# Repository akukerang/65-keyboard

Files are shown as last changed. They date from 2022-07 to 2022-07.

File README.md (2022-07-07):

# 65-keyboard
- 65% keyboard PCB for PCB design practice. 
- Used masterzen's guide for keyboard design: https://www.masterzen.fr/2020/05/03/designing-a-keyboard-part-1/
- Probably not going to add LEDs, too much routing.
## Pictures
### PCB Design
PCB Design
### PCB Top
PCB Top
### PCB Bottom
PCB Bottom

Poom

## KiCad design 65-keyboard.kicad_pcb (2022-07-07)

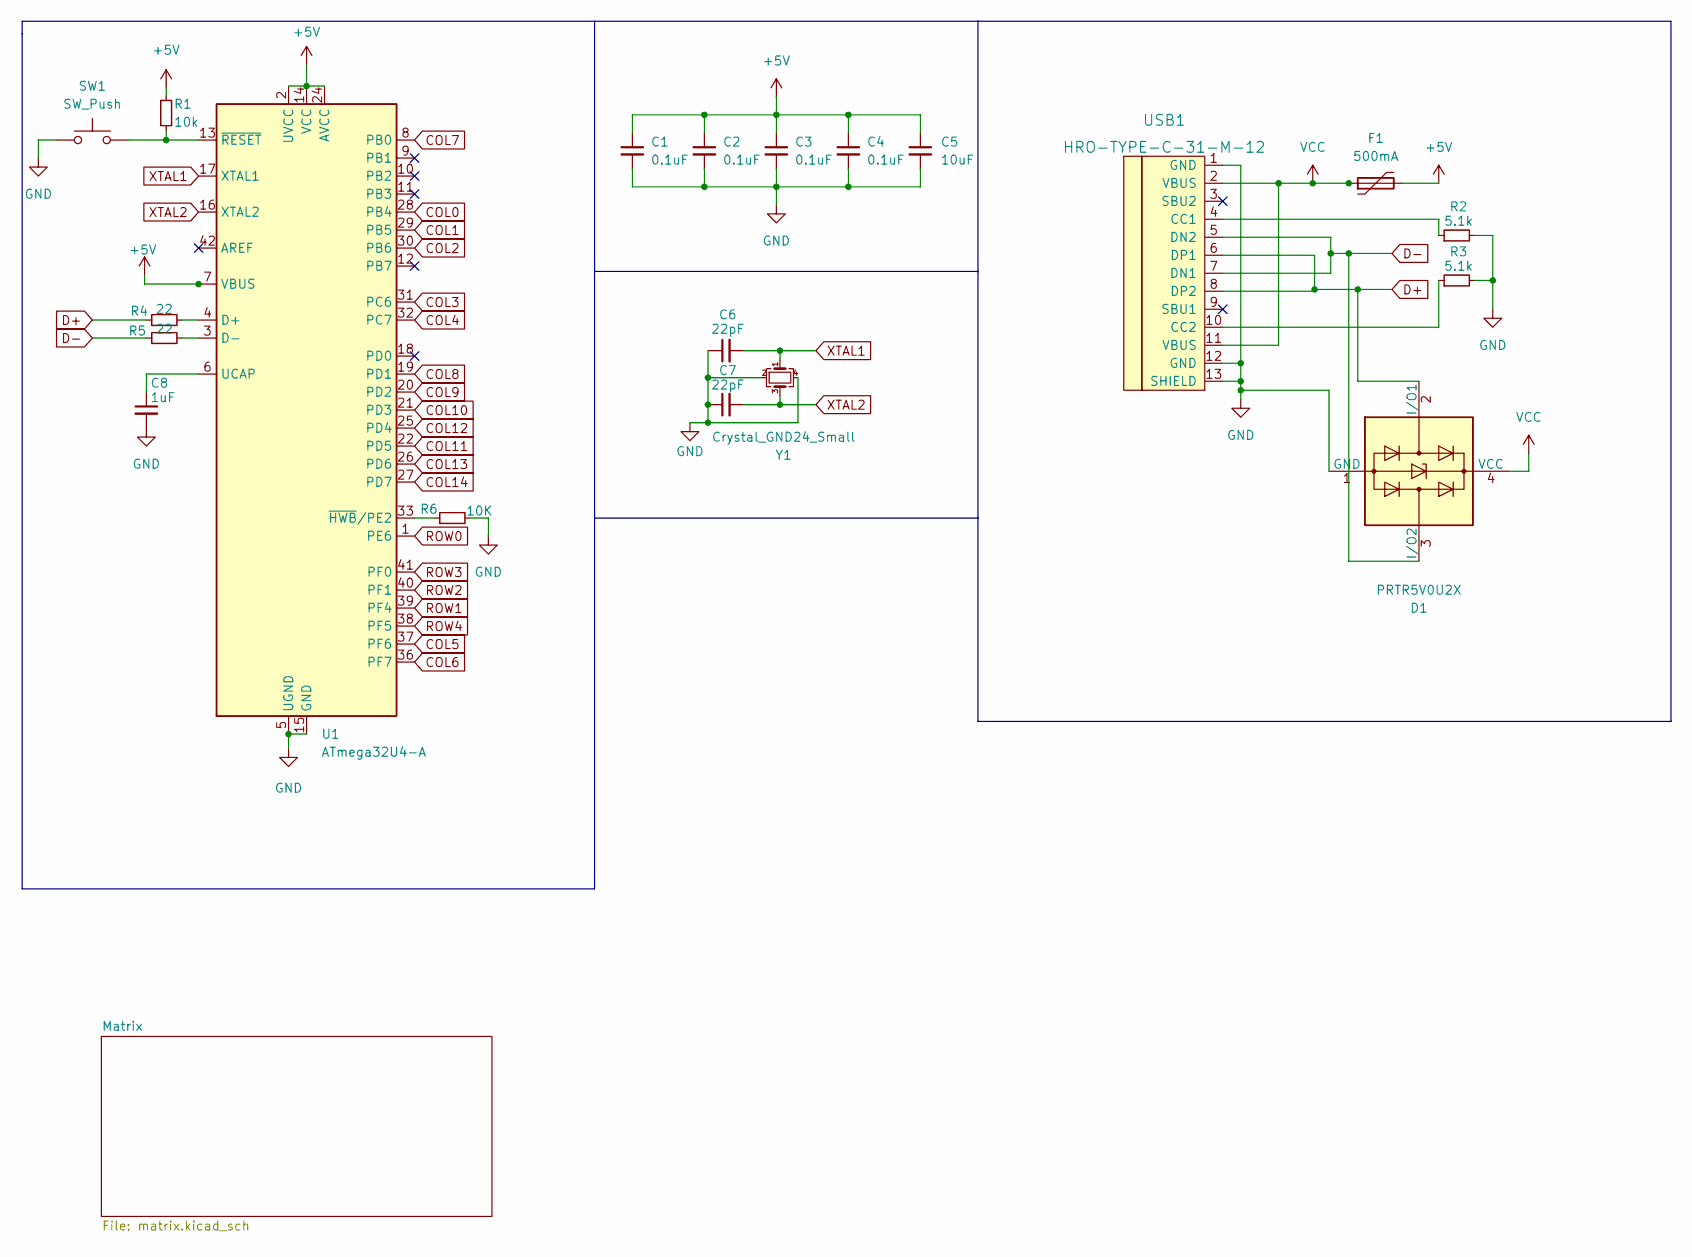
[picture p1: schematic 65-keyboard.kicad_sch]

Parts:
C1, C2, C3, C4: 0.1uF; C_0805_2012Metric_Pad1.18x1.45mm_HandSolder
C5: 10uF; C_0805_2012Metric_Pad1.18x1.45mm_HandSolder
C6, C7: 22pF; C_0805_2012Metric_Pad1.18x1.45mm_HandSolder
C8: 1uF; C_0805_2012Metric_Pad1.18x1.45mm_HandSolder
D1: PRTR5V0U2X; SOT143B
F1: 500mA; Fuse_1206_3216Metric_Pad1.42x1.75mm_HandSolder
R1: 10k; R_0805_2012Metric_Pad1.20x1.40mm_HandSolder
R2, R3: 5.1k; R_0805_2012Metric_Pad1.20x1.40mm_HandSolder
R4, R5: 22; R_0805_2012Metric_Pad1.20x1.40mm_HandSolder
R6: 10K; R_0805_2012Metric_Pad1.20x1.40mm_HandSolder
SW1: SW_Push; SW_SPST_SKQG_WithStem
U1: ATmega32U4-A; TQFP-44_10x10mm_P0.8mm
USB1: HRO-TYPE-C-31-M-12; HRO-TYPE-C-31-M-12-HandSoldering
Y1: Crystal_GND24_Small; Crystal_SMD_3225-4Pin_3.2x2.5mm_HandSoldering

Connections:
+5V: C1.1, C2.1, C3.1, C4.1, C5.1, F1.2, R1.1, U1.2 (UVCC), U1.7 (VBUS), U1.14 (VCC), U1.24 (AVCC), U1.34 (VCC), U1.44 (AVCC)
COL0: U1.28 (PB4); also elsewhere on the board
COL1: U1.29 (PB5); also elsewhere on the board
COL2: U1.30 (PB6); also elsewhere on the board
COL3: U1.31 (PC6); also elsewhere on the board
COL4: U1.32 (PC7); also elsewhere on the board
COL5: U1.37 (PF6); also elsewhere on the board
COL6: U1.36 (PF7); also elsewhere on the board
COL7: U1.8 (PB0); also elsewhere on the board
COL8: U1.19 (PD1); also elsewhere on the board
COL9: U1.20 (PD2); also elsewhere on the board
COL10: U1.21 (PD3); also elsewhere on the board
COL11: U1.22 (PD5); also elsewhere on the board
COL12: U1.25 (PD4); also elsewhere on the board
COL13: U1.26 (PD6); also elsewhere on the board
COL14: U1.27 (PD7); also elsewhere on the board
D+: D1.2 (I/O1), R4.1, USB1.6 (DP1), USB1.8 (DP2)
D-: D1.3 (I/O2), R5.1, USB1.5 (DN2), USB1.7 (DN1)
GND: C1.2, C2.2, C3.2, C4.2, C5.2, C6.1, C7.1, C8.2, D1.1 (GND), R2.2, R3.2, R6.2, SW1.1, U1.5 (UGND), U1.15 (GND), U1.23 (GND), U1.35 (GND), U1.43 (GND), USB1.1 (GND), USB1.12 (GND), USB1.13 (SHIELD), Y1.2, Y1.4
unnamed: C8.1, U1.6 (UCAP)
unnamed: R1.2, SW1.2, U1.13 (~RESET)
unnamed: R2.1, USB1.4 (CC1)
unnamed: R3.1, USB1.10 (CC2)
unnamed: R4.2, U1.4 (D+)
unnamed: R5.2, U1.3 (D-)
unnamed: R6.1, U1.33 (~HWB/PE2)
ROW0: U1.1 (PE6); also elsewhere on the board
ROW1: U1.39 (PF4); also elsewhere on the board
ROW2: U1.40 (PF1); also elsewhere on the board
ROW3: U1.41 (PF0); also elsewhere on the board
ROW4: U1.38 (PF5); also elsewhere on the board
VCC: D1.4 (VCC), F1.1, USB1.2 (VBUS), USB1.11 (VBUS)
XTAL1: C6.2, U1.17 (XTAL1), Y1.1
XTAL2: C7.2, U1.16 (XTAL2), Y1.3

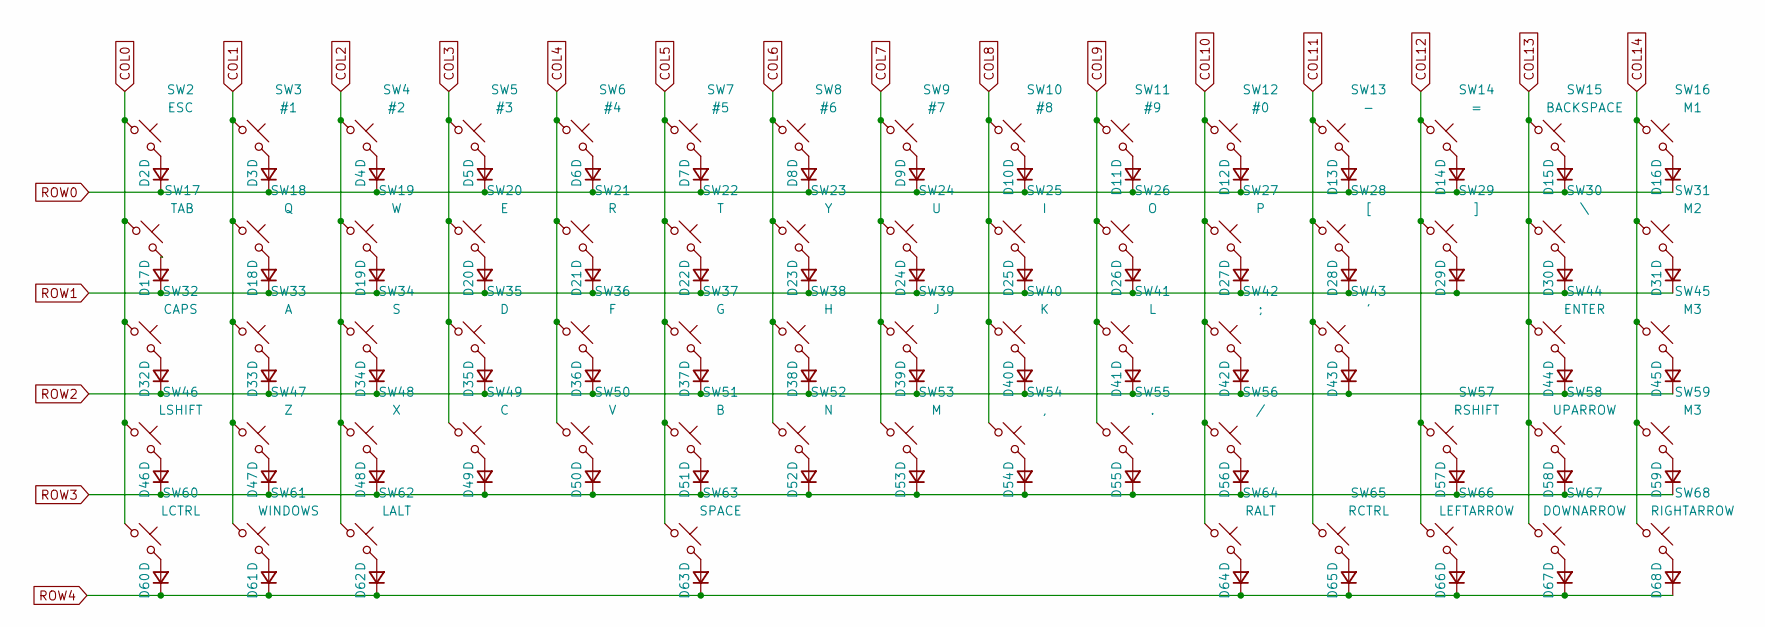
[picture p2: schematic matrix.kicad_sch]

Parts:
D2, D3, D4, D5, D6, D7, D8, D9, D10, D11, D12, D13, D14, D15, D16, D17, D18, D19, D20, D21, D22, D23, D24, D25, D26, D27, D28, D29, D30, D31, D32, D33, D34, D35, D36, D37, D38, D39, D40, D41, D42, D43, D44, D45, D46, D47, D48, D49, D50, D51, D52, D53, D54, D55, D56, D57, D58, D59, D60, D61, D62, D63, D64, D65, D66, D67, D68: D; D_SOD-123
SW2: ESC; SW_MX_1u
SW3: #1; SW_MX_1u
SW4: #2; SW_MX_1u
SW5: #3; SW_MX_1u
SW6: #4; SW_MX_1u
SW7: #5; SW_MX_1u
SW8: #6; SW_MX_1u
SW9: #7; SW_MX_1u
SW10: #8; SW_MX_1u
SW11: #9; SW_MX_1u
SW12: #0; SW_MX_1u
SW13: -; SW_MX_1u
SW14: =; SW_MX_1u
SW15: BACKSPACE; SW_MX_1u
SW16: M1; SW_MX_1u
SW17: TAB; SW_MX_1.5u
SW18: Q; SW_MX_1u
SW19: W; SW_MX_1u
SW20: E; SW_MX_1u
SW21: R; SW_MX_1u
SW22: T; SW_MX_1u
SW23: Y; SW_MX_1u
SW24: U; SW_MX_1u
SW25: I; SW_MX_1u
SW26: O; SW_MX_1u
SW27: P; SW_MX_1u
SW28: [; SW_MX_1u
SW29: ]; SW_MX_1u
SW30: \; SW_MX_1.5u
SW31: M2; SW_MX_1u
SW32: CAPS; SW_MX_1.75u
SW33: A; SW_MX_1u
SW34: S; SW_MX_1u
SW35: D; SW_MX_1u
SW36: F; SW_MX_1u
SW37: G; SW_MX_1u
SW38: H; SW_MX_1u
SW39: J; SW_MX_1u
SW40: K; SW_MX_1u
SW41: L; SW_MX_1u
SW42: ;; SW_MX_1u
SW43: '; SW_MX_1u
SW44: ENTER; SW_MX_1u
SW45, SW59: M3; SW_MX_1u
SW46: LSHIFT; SW_MX_1u
SW47: Z; SW_MX_1u
SW48: X; SW_MX_1u
SW49: C; SW_MX_1u
SW50: V; SW_MX_1u
SW51: B; SW_MX_1u
SW52: N; SW_MX_1u
SW53: M; SW_MX_1u
SW54: ,; SW_MX_1u
SW55: .; SW_MX_1u
SW56: /; SW_MX_1u
SW57: RSHIFT; SW_MX_1.75u
SW58: UPARROW; SW_MX_1u
SW60: LCTRL; SW_MX_1.25u
SW61: WINDOWS; SW_MX_1.25u
SW62: LALT; SW_MX_1.25u
SW63: SPACE; SW_MX_1u
SW64: RALT; SW_MX_1.25u
SW65: RCTRL; SW_MX_1.25u
SW66: LEFTARROW; SW_MX_1u
SW67: DOWNARROW; SW_MX_1u
SW68: RIGHTARROW; SW_MX_1u

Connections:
COL0: SW2.1, SW17.1, SW32.1, SW46.1, SW60.1; also elsewhere on the board
COL1: SW3.1, SW18.1, SW33.1, SW47.1, SW61.1; also elsewhere on the board
COL2: SW4.1, SW19.1, SW34.1, SW48.1, SW62.1; also elsewhere on the board
COL3: SW5.1, SW20.1, SW35.1, SW49.1; also elsewhere on the board
COL4: SW6.1, SW21.1, SW36.1, SW50.1; also elsewhere on the board
COL5: SW7.1, SW22.1, SW37.1, SW51.1, SW63.1; also elsewhere on the board
COL6: SW8.1, SW23.1, SW38.1, SW52.1; also elsewhere on the board
COL7: SW9.1, SW24.1, SW39.1, SW53.1; also elsewhere on the board
COL8: SW10.1, SW25.1, SW40.1, SW54.1; also elsewhere on the board
COL9: SW11.1, SW26.1, SW41.1, SW55.1; also elsewhere on the board
COL10: SW12.1, SW27.1, SW42.1, SW56.1, SW64.1; also elsewhere on the board
COL11: SW13.1, SW28.1, SW43.1, SW65.1; also elsewhere on the board
COL12: SW14.1, SW29.1, SW57.1, SW66.1; also elsewhere on the board
COL13: SW15.1, SW30.1, SW44.1, SW58.1, SW67.1; also elsewhere on the board
COL14: SW16.1, SW31.1, SW45.1, SW59.1, SW68.1; also elsewhere on the board
unnamed: D2.2 (A), SW2.2
unnamed: D3.2 (A), SW3.2
unnamed: D4.2 (A), SW4.2
unnamed: D5.2 (A), SW5.2
unnamed: D6.2 (A), SW6.2
unnamed: D7.2 (A), SW7.2
unnamed: D8.2 (A), SW8.2
unnamed: D9.2 (A), SW9.2
unnamed: D10.2 (A), SW10.2
unnamed: D11.2 (A), SW11.2
unnamed: D12.2 (A), SW12.2
unnamed: D13.2 (A), SW13.2
unnamed: D14.2 (A), SW14.2
unnamed: D15.2 (A), SW15.2
unnamed: D16.2 (A), SW16.2
unnamed: D17.2 (A), SW17.2
unnamed: D18.2 (A), SW18.2
unnamed: D19.2 (A), SW19.2
unnamed: D20.2 (A), SW20.2
unnamed: D21.2 (A), SW21.2
unnamed: D22.2 (A), SW22.2
unnamed: D23.2 (A), SW23.2
unnamed: D24.2 (A), SW24.2
unnamed: D25.2 (A), SW25.2
unnamed: D26.2 (A), SW26.2
unnamed: D27.2 (A), SW27.2
unnamed: D28.2 (A), SW28.2
unnamed: D29.2 (A), SW29.2
unnamed: D30.2 (A), SW30.2
unnamed: D31.2 (A), SW31.2
unnamed: D32.2 (A), SW32.2
unnamed: D33.2 (A), SW33.2
unnamed: D34.2 (A), SW34.2
unnamed: D35.2 (A), SW35.2
unnamed: D36.2 (A), SW36.2
unnamed: D37.2 (A), SW37.2
unnamed: D38.2 (A), SW38.2
unnamed: D39.2 (A), SW39.2
unnamed: D40.2 (A), SW40.2
unnamed: D41.2 (A), SW41.2
unnamed: D42.2 (A), SW42.2
unnamed: D43.2 (A), SW43.2
unnamed: D44.2 (A), SW44.2
unnamed: D45.2 (A), SW45.2
unnamed: D46.2 (A), SW46.2
unnamed: D47.2 (A), SW47.2
unnamed: D48.2 (A), SW48.2
unnamed: D49.2 (A), SW49.2
unnamed: D50.2 (A), SW50.2
unnamed: D51.2 (A), SW51.2
unnamed: D52.2 (A), SW52.2
unnamed: D53.2 (A), SW53.2
unnamed: D54.2 (A), SW54.2
unnamed: D55.2 (A), SW55.2
unnamed: D56.2 (A), SW56.2
unnamed: D57.2 (A), SW57.2
unnamed: D58.2 (A), SW58.2
unnamed: D59.2 (A), SW59.2
unnamed: D60.2 (A), SW60.2
unnamed: D61.2 (A), SW61.2
unnamed: D62.2 (A), SW62.2
unnamed: D63.2 (A), SW63.2
unnamed: D64.2 (A), SW64.2
unnamed: D65.2 (A), SW65.2
unnamed: D66.2 (A), SW66.2
unnamed: D67.2 (A), SW67.2
unnamed: D68.2 (A), SW68.2
ROW0: D2.1 (K), D3.1 (K), D4.1 (K), D5.1 (K), D6.1 (K), D7.1 (K), D8.1 (K), D9.1 (K), D10.1 (K), D11.1 (K), D12.1 (K), D13.1 (K), D14.1 (K), D15.1 (K), D16.1 (K); also elsewhere on the board
ROW1: D17.1 (K), D18.1 (K), D19.1 (K), D20.1 (K), D21.1 (K), D22.1 (K), D23.1 (K), D24.1 (K), D25.1 (K), D26.1 (K), D27.1 (K), D28.1 (K), D29.1 (K), D30.1 (K), D31.1 (K); also elsewhere on the board
ROW2: D32.1 (K), D33.1 (K), D34.1 (K), D35.1 (K), D36.1 (K), D37.1 (K), D38.1 (K), D39.1 (K), D40.1 (K), D41.1 (K), D42.1 (K), D43.1 (K), D44.1 (K), D45.1 (K); also elsewhere on the board
ROW3: D46.1 (K), D47.1 (K), D48.1 (K), D49.1 (K), D50.1 (K), D51.1 (K), D52.1 (K), D53.1 (K), D54.1 (K), D55.1 (K), D56.1 (K), D57.1 (K), D58.1 (K), D59.1 (K); also elsewhere on the board
ROW4: D60.1 (K), D61.1 (K), D62.1 (K), D63.1 (K), D64.1 (K), D65.1 (K), D66.1 (K), D67.1 (K), D68.1 (K); also elsewhere on the board

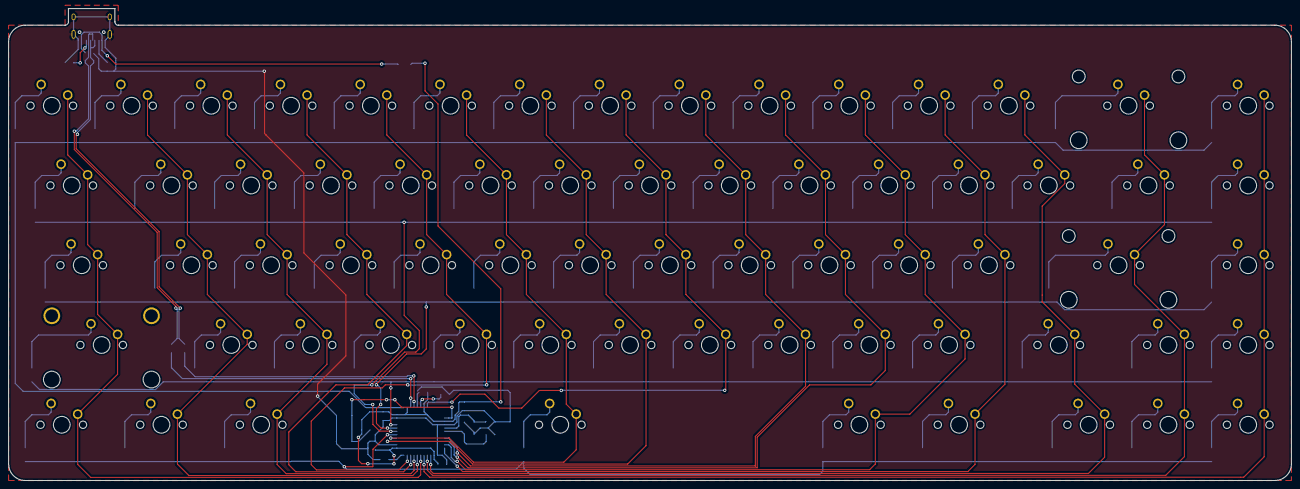
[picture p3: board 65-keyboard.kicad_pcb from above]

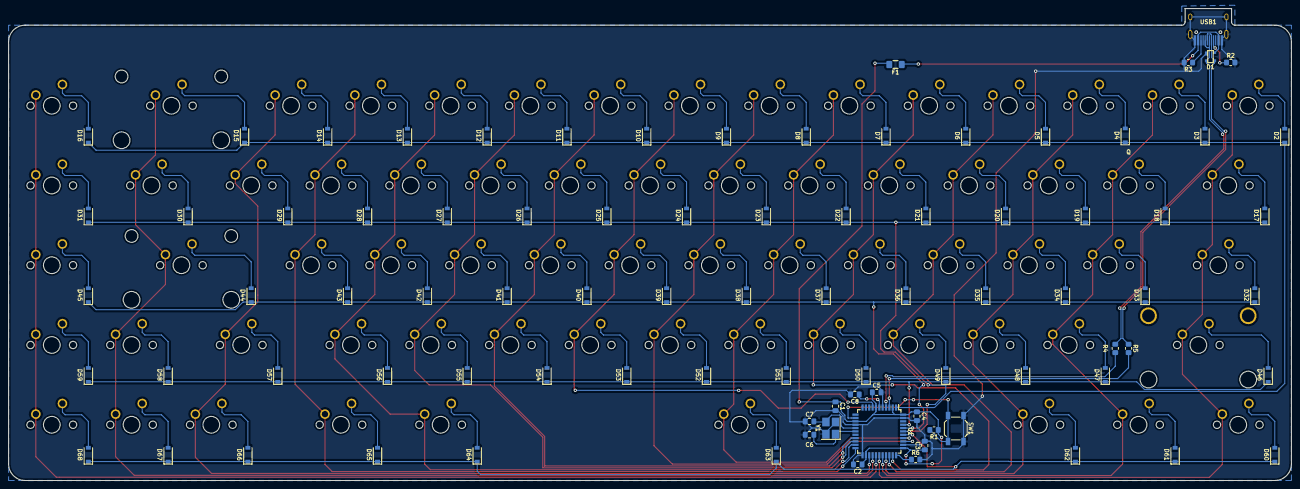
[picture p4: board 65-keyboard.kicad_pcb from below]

Board: 2 copper layers, 306.4 x 112.7 mm, 154 parts (154 on the bottom side), 101 nets.

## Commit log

2022-07-03 Init commit
    [65-keyboard.kicad_pcb, 65-keyboard.kicad_sch]
2022-07-03 Schematic progress
    MCU, USB-C, Crystal done. Also added USB-C submodule.
    [65-keyboard.kicad_sch]
2022-07-03 Matrix Schematic
    [65-keyboard.kicad_sch, matrix.kicad_sch]
2022-07-03 MCU Schematic Finish
    [65-keyboard.kicad_sch, matrix.kicad_sch]
2022-07-04 PCB start, schematic mostly finished
    [65-keyboard.kicad_pcb, matrix.kicad_sch]
2022-07-04 PCB Outline
    Switches placed in correct areas mostly. Still need to route and place components.
    [65-keyboard.kicad_pcb, 65-keyboard.kicad_sch, matrix.kicad_sch]
2022-07-04 more routing
    [65-keyboard.kicad_pcb, 65-keyboard.kicad_sch]
2022-07-05 routing "finished"
    DRC still returns issues, but routing is done.
    [65-keyboard.kicad_pcb]
2022-07-06 rerouted pcb
    fixing drc issues
    [65-keyboard.kicad_pcb, 65-keyboard.kicad_sch, matrix.kicad_sch]
2022-07-06 More routing
    Still need to connect all the 5v and GND
    [65-keyboard.kicad_pcb]
2022-07-07 PCB Routing finish
    [65-keyboard.kicad_pcb]
2022-07-07 USB-C 3D model
    Added USB-C 3d model to the footprint in 3d viewer
